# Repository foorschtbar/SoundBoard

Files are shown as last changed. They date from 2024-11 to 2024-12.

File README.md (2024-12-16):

# SoundBoard

A simple PCB with two audio drivers, a SD card reader and a ESP32 microcontroller to play sounds via MQTT.

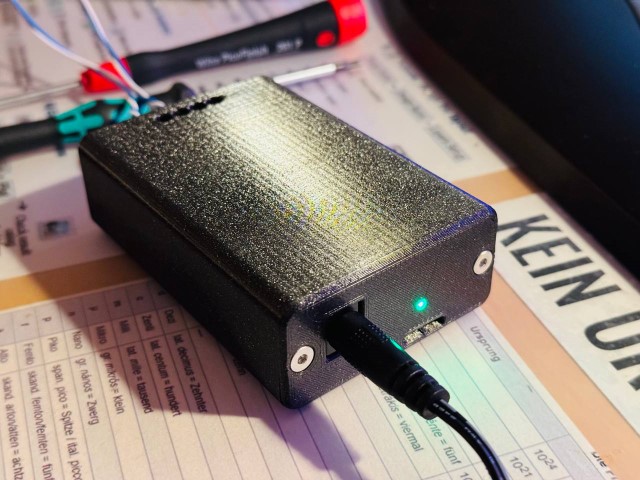
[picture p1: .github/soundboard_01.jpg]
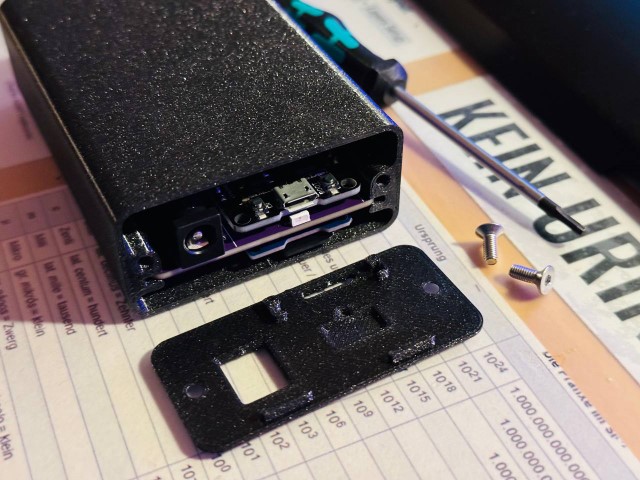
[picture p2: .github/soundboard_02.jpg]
 
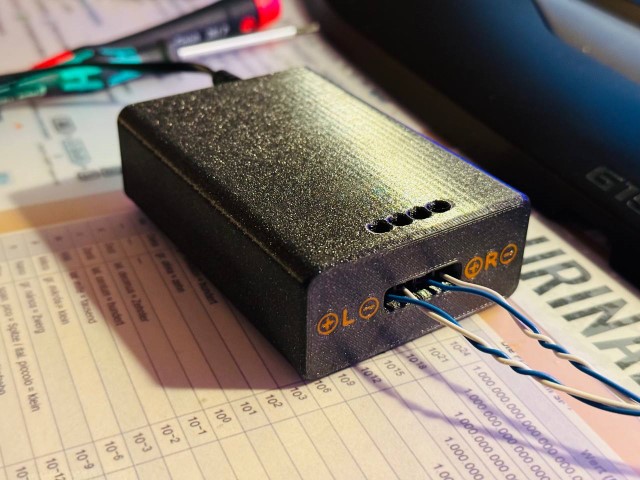
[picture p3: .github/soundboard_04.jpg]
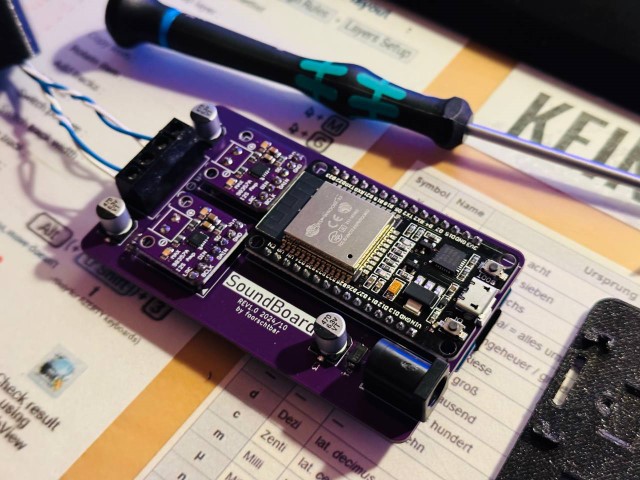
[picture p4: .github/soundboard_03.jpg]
 
## Features
- On factory settings or no known WiFi SSID is found, device starts in AP mode
  - To stay in AP mode, leave the SSID and password empty
- The LED show the status of the device
  - `Orange`: Booting
  - `Blue`: Connecting to WiFi
  - `Green`: Connected to existing WiFi
  - `Violet`: Started WiFi AP
  - `Red`: No connection to WiFi
  - `White`: Web or MQTT activity
- The device can be controlled via MQTT:
  - Subscripte to `<prefix>/status` to get the status of the device
  - Publish to `<prefix>/cmd` to play a sound
    - `{"play": "filename.mp3", "volume": 50, "balance": 0}` (volume and balance are optional)
    - `{"tts": "Hello World", "lang": "de"}`

## Getting Started

- Default WiFi SSID: `SoundBoard`
- Default WiFi Password: `12345678x!`
  
## Hardware

### Case

- The case could be found on [Printables](https://www.printables.com/model/1072334-soundboard).

### PCB

- The PCB was designed with KiCad and could be found in the `pcb` directory.

## Development
### Frontend development

- Start the frontend development server with `python .\webserver.py` in the `html` directory.
- Open the browser at `http://localhost:8000/` to see the frontend.
- Set manual a cookie with `overwrite-host` to the hostname or ip of the device and reload the page.

### ToDos/Improvement Ideas

- [ ] Add a priority flag to the MQTT messages. Stop the current playback only if the priority is higher than the current one.
- [ ] Sync volume and balance fader across all clients
- [ ] Enable/Disable Playback/Stop buttons based on the current state
- [ ] Add addidtional MQTT topics with hostname for status und command
- [ ] Refactor Code in more separat files
- [ ] Maybe: Option to queue playbacks
- [x] Send file list in multiple messages
- [x] If we had valid settings, but in fallback AP mode, try to connect to the last known wifi periodically
- [x] Download audiofiles from the webinterface
- [x] Replace play/delete/download with icons?
- [x] Add tailing slash to the topic prefix
- [x] Save authentication in cookie/webstore
- [x] Add credentials to post requests
- [x] Improve MQTT reconnection and resubscription
- [x] Improve MQTT reconnection after boot when no connection is available
- [x] Make MQTT status topic more "chatty"

## Links
- [ESP32 Based Internet Radio using MAX98357A I2S Amplifier Board](https://circuitdigest.com/microcontroller-projects/esp32-based-internet-radio-using-max98357a-i2s-amplifier-board)
- [I2S Sound Tutorial for ESP32 - DIYI0T](https://diyi0t.com/i2s-sound-tutorial-for-esp32/)
- [schreibfaul1/ESP32-audioI2S: Play mp3 files from SD via I2S](https://github.com/schreibfaul1/ESP32-audioI2S)
- [ESP32 Pinout Reference: Which GPIO pins should you use? | Random Nerd Tutorials](https://randomnerdtutorials.com/esp32-pinout-reference-gpios/)
- [ESP32 partition calculator: Easily Calculate ESP32 Memory and Partition Sizes](https://esp32.jgarrettcorbin.com/)

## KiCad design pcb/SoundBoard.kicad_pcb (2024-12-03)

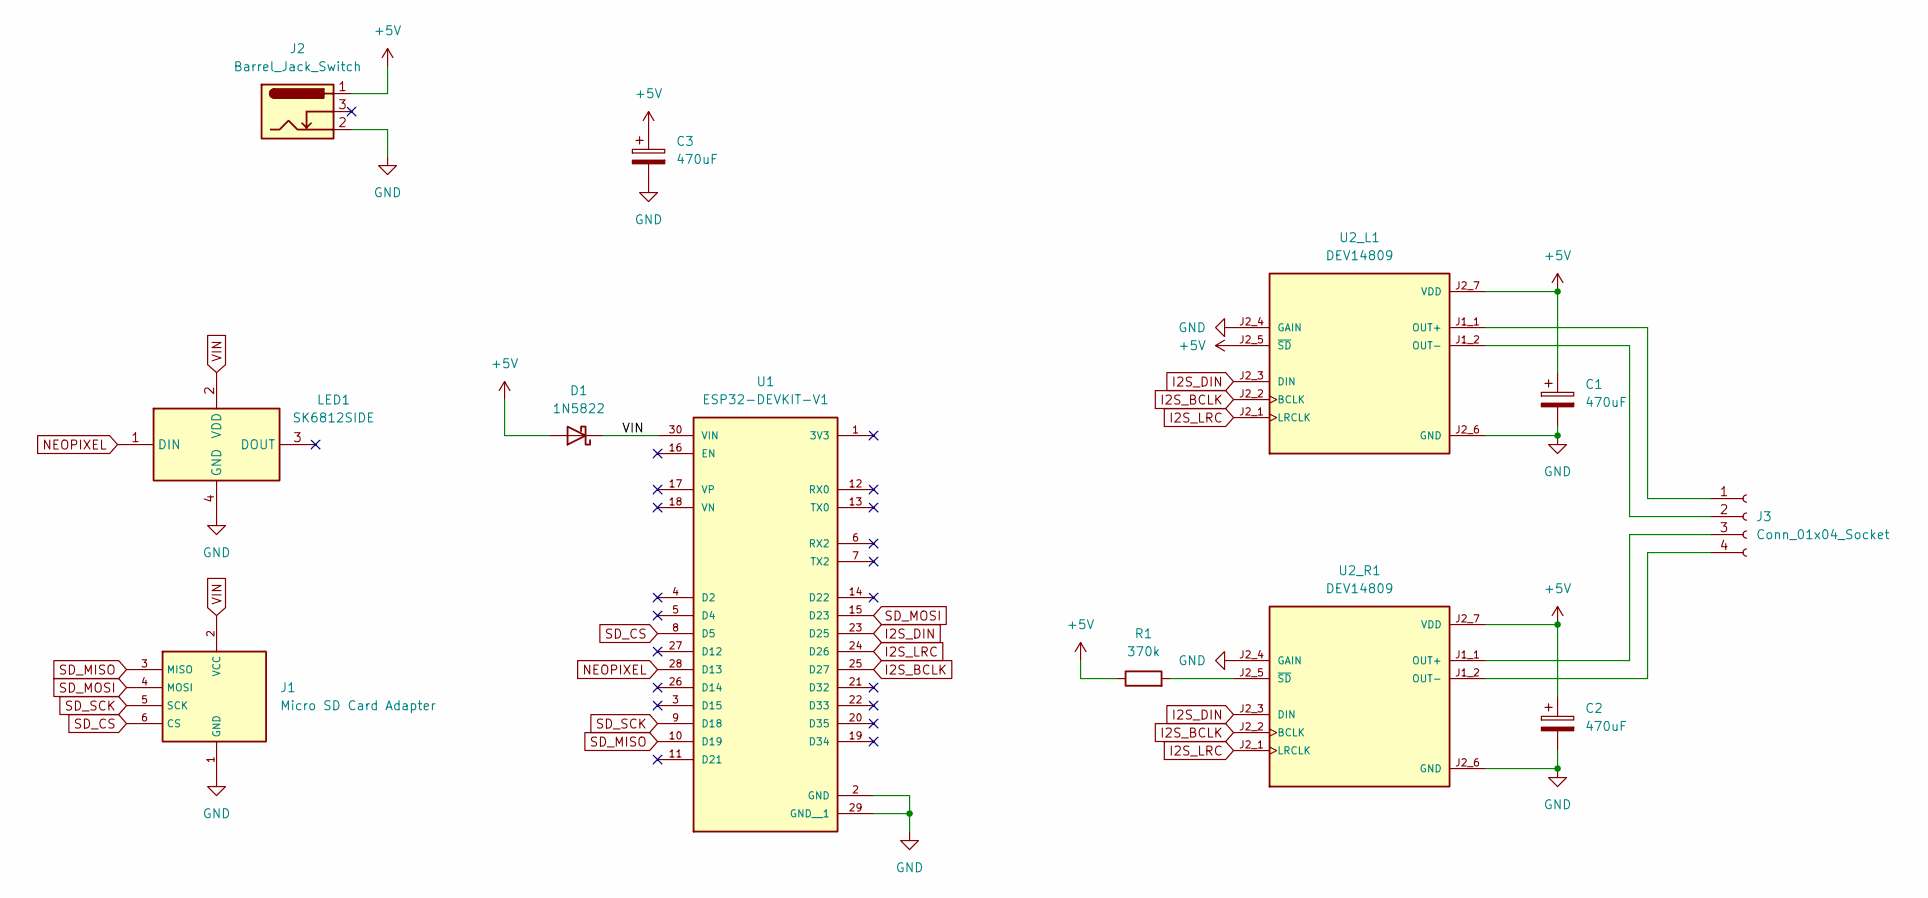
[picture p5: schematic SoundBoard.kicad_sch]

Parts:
C1, C2, C3: 470uF; C_Elec_6.3x7.7
D1: 1N5822; D_SMA_Handsoldering
J1: Micro SD Card Adapter; SDCardAdapter
J2: Barrel_Jack_Switch; BarrelJack_Horizontal
J3: Conn_01x04_Socket; TerminalBlock_Phoenix_MKDS-1,5-4-5.08_1x04_P5.08mm_Horizont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
LED1: SK6812SIDE; Manufacturer_Part_Number SK6812SIDE
R1: 370k; R_0805_2012Metric_Pad1.20x1.40mm_HandSolder
U1: ESP32-DEVKIT-V1; ESP32_DEVKIT_V1; PARTREV N/A
U2_L1, U2_R1: DEV14809; MAX98357A; PARTREV 1.2

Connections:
+5V: C1.1, C2.1, C3.1, D1.2 (A), J2.1, R1.1, U2_L1.J2_5 (~SD), U2_L1.J2_7 (VDD), U2_R1.J2_7 (VDD)
GND: C1.2, C2.2, C3.2, J1.1 (GND), J2.2, LED1.4 (GND), U1.2 (GND), U1.29 (GND__1), U2_L1.J2_4 (GAIN), U2_L1.J2_6 (GND), U2_R1.J2_4 (GAIN), U2_R1.J2_6 (GND)
I2S_BCLK: U1.25 (D27), U2_L1.J2_2 (BCLK), U2_R1.J2_2 (BCLK)
I2S_DIN: U1.23 (D25), U2_L1.J2_3 (DIN), U2_R1.J2_3 (DIN)
I2S_LRC: U1.24 (D26), U2_L1.J2_1 (LRCLK), U2_R1.J2_1 (LRCLK)
NEOPIXEL: LED1.1 (DIN), U1.28 (D13)
unnamed: J3.1, U2_L1.J1_1 (OUT+)
unnamed: J3.2, U2_L1.J1_2 (OUT-)
unnamed: J3.3, U2_R1.J1_1 (OUT+)
unnamed: J3.4, U2_R1.J1_2 (OUT-)
unnamed: R1.2, U2_R1.J2_5 (~SD)
SD_CS: J1.6 (CS), U1.8 (D5)
SD_MISO: J1.3 (MISO), U1.10 (D19)
SD_MOSI: J1.4 (MOSI), U1.15 (D23)
SD_SCK: J1.5 (SCK), U1.9 (D18)
VIN: D1.1 (K), J1.2 (VCC), LED1.2 (VDD), U1.30 (VIN)

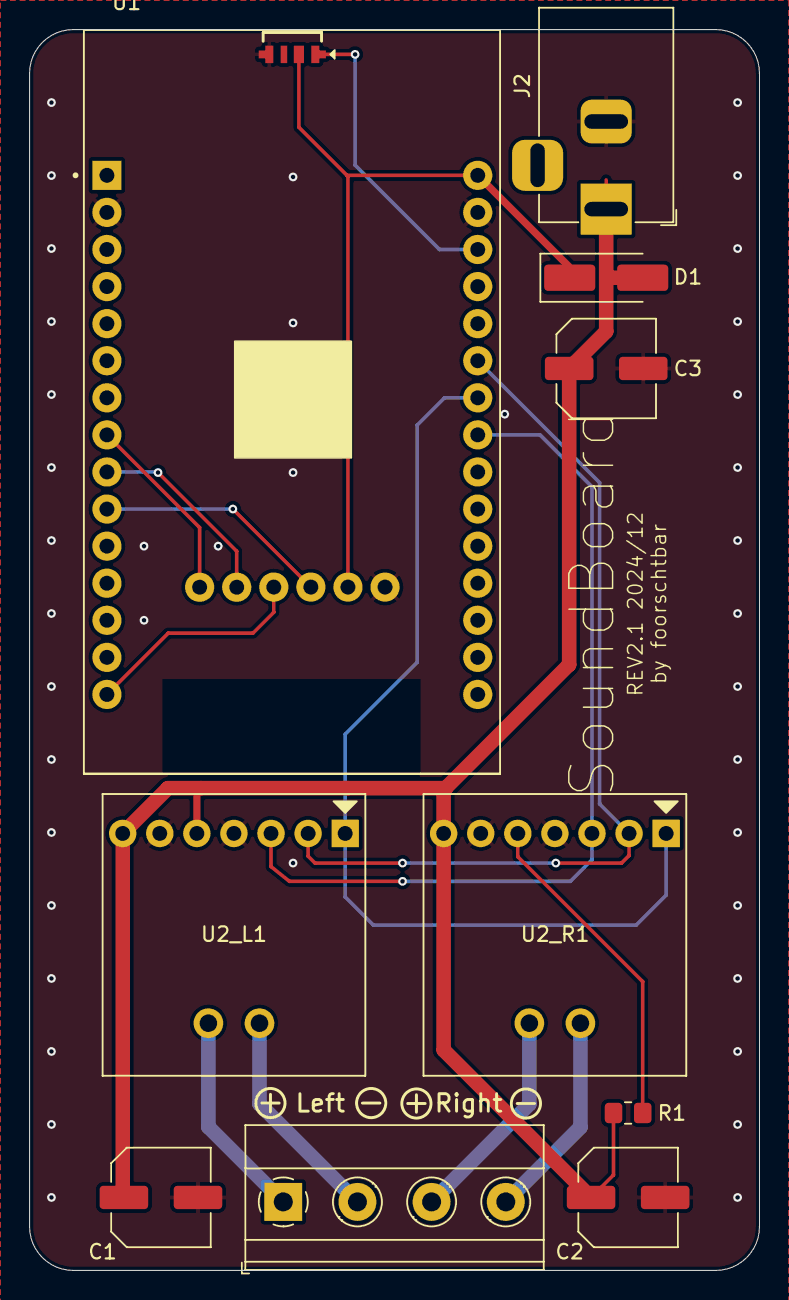
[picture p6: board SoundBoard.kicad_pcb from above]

Board: 2 copper layers, 50.0 x 85.0 mm, 12 parts (1 on the bottom side), 16 nets.

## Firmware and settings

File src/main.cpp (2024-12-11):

#include "Arduino.h"
#include <ArduinoJson.h>
#include "Audio.h"
#include "SD.h"
#include <LittleFS.h>
#include <AsyncTCP.h>
#include <ESPAsyncWebServer.h>
#include <Update.h>
#include <SPI.h>
#include <FS.h>
#include "SingleLED.h"
#include "util.h"
// #include <index.h>
#include <mqtt.h>
#include "esp32/rom/rtc.h"

// I2S Pins
#define I2S_DOUT 25
#define I2S_LRC 26
#define I2S_BCLK 27
// SD Card Pins
#define SD_CS 5
#define SPI_SCK 18
#define SPI_MISO 19
#define SPI_MOSI 23
// Other Pins
#define LED 2 // Blue onboard LED
#define NEOPIXEL 13

// Defaul values
#define BRIGHTNESS_DEFAULT 50
#define DEFAULT_HOSTNAME "SoundBoard"
#define WIFI_AP_SSID "SoundBoard"
#define WIFI_AP_PSK "12345678x!"
#define WIFI_TIMEOUT 1000 * 10               // 10 seconds
#define WIFI_RECONNECT_TIMEOUT 1000 * 60 * 5 // 5 minutes
#define PASSWORD_HIDDEN "**********"
#define MQTT_TOPIC_CMD "cmd"
#define MQTT_TOPIC_STATUS "status"
#define SYSINFO_UPDATE_INTERVAL 1000 * 30
#define FILELIST_CHUNK_SIZE 10
#define DEFAULT_USERNAME "admin"
#define DEFAULT_PASSWORD "admin"
#define DEFAULT_VOLUME 5
#define DEFAULT_BALANCE 0
#define DEFAULT_MQTT_TOPIC_PREFIX "soundboard/"
#define DEFAULT_MQTT_PORT "1883"

// Audioplay
Audio audio;
// LED
SingleLED led(NEOPIXEL, NEO_GRB + NEO_KHZ800);
// MQTT Client
WiFiClient espClient;
MQTT mqtt(espClient);

// Webserver
AsyncWebServer server(80);
AsyncWebSocket websocket("/ws");
std::vector<uint32_t> authenticatedClients;

// Variables
int currentVolume = DEFAULT_VOLUME;
int currentBalance = DEFAULT_BALANCE;

// Settings
bool settingsValid = false;
String settings_ssid;
String settings_psk;
String settings_hostname = DEFAULT_HOSTNAME;
String settings_mqtt_broker;
String settings_mqtt_port = DEFAULT_MQTT_PORT;
String settings_mqtt_user;
String settings_mqtt_pass;
String settings_mqtt_prefix = DEFAULT_MQTT_TOPIC_PREFIX;
String settings_username = DEFAULT_USERNAME;
String settings_password = DEFAULT_PASSWORD;
int settings_volume = DEFAULT_VOLUME;   // 0-21
int settings_balance = DEFAULT_BALANCE; // -16 to 16
bool shouldReboot = false;              // flag to use from web update to reboot the ESP
unsigned long lastSysInfoUpdate = 0;
unsigned long lastWifiReconnect = 0;
bool fsInternalMounted = false;
bool fsExternalMounted = false;

extern const uint8_t file_index_html_start[] asm("_binary_html_index_html_gz_start");
extern const uint8_t file_index_html_end[] asm("_binary_html_index_html_gz_end");

typedef enum DATA_TYPE
{
  DATA_SYSINFO,
  DATA_ALL,
  DATA_FILES
} sendDataType;

void showAction()
{
  led.blink(100, 255, 255, 255);
}

void readSettings()
{

  if (!FILESYSTEM.exists("/settings.json"))
  {
    logln(F("Settings file not found"));
    return;
  }

  // Open the file for reading
  File file = FILESYSTEM.open("/settings.json", "r");

  if (!file)
  {
    logln(F("Failed to open file for reading"));
    return;
  }

  // Allocate a temporary JsonDocument
  StaticJsonDocument<512> doc;

  // Parse the JSON data from the file
  DeserializationError error = deserializeJson(doc, file);

  if (error)
  {
    logln(F("Failed to parse JSON"));
    return;
  }
  else
  {
    if (doc.containsKey("ssid"))
    {
      settings_ssid = doc["ssid"].as<String>();
    }
    if (doc.containsKey("psk"))
    {
      settings_psk = doc["psk"].as<String>();
    }
    if (doc.containsKey("hostname"))
    {
      settings_hostname = doc["hostname"].as<String>();
    }
    if (doc.containsKey("username"))
    {
      settings_username = doc["username"].as<String>();
    }
    if (doc.containsKey("password"))
    {
      settings_password = doc["password"].as<String>();
    }
    if (doc.containsKey("volume"))
    {
      settings_volume = doc["volume"].as<int>();
      currentVolume = settings_volume;
    }
    if (doc.containsKey("balance"))
    {
      settings_balance = doc["balance"].as<int>();
      currentBalance = settings_balance;
    }
    if (doc.containsKey("mqtt_broker"))
    {
      settings_mqtt_broker = doc["mqtt_broker"].as<String>();
    }
    if (doc.containsKey("mqtt_port"))
    {
      settings_mqtt_port = doc["mqtt_port"].as<String>();
    }
    if (doc.containsKey("mqtt_user"))
    {
      settings_mqtt_user = doc["mqtt_user"].as<String>();
    }
    if (doc.containsKey("mqtt_pass"))
    {
      settings_mqtt_pass = doc["mqtt_pass"].as<String>();
    }
    if (doc.containsKey("mqtt_prefix"))
    {
      settings_mqtt_prefix = doc["mqtt_prefix"].as<String>();
    }

    settingsValid = true;
  }

  // Close the file
  file.close();
}

void writeSettings()
{
  // Allocate a temporary JsonDocument
  StaticJsonDocument<512> doc;

  doc["ssid"] = settings_ssid;
  doc["psk"] = settings_psk;
  doc["hostname"] = settings_hostname;
  doc["username"] = settings_username;
  doc["password"] = settings_password;
  doc["volume"] = settings_volume;
  doc["balance"] = settings_balance;
  doc["mqtt_broker"] = settings_mqtt_broker;
  doc["mqtt_port"] = settings_mqtt_port;
  doc["mqtt_user"] = settings_mqtt_user;
  doc["mqtt_pass"] = settings_mqtt_pass;

  // trim mqtt_prefix
  settings_mqtt_prefix.trim();
  // check if mqtt_prefix ends with a slash
  if (settings_mqtt_prefix[settings_mqtt_prefix.length() - 1] != '/')
  {
    settings_mqtt_prefix += "/";
  }
  doc["mqtt_prefix"] = settings_mqtt_prefix;

  // Open the file for writing
  File file = FILESYSTEM.open("/settings.json", "w");
  if (!file)
  {
    logln(F("Failed to open file for writing"));
    return;
  }

  // Serialize JSON to file
  if (serializeJson(doc, file) == 0)
  {
    logln(F("Failed to write to file"));
  }
}

bool checkCredentials(AsyncWebServerRequest *request)
{
  if (request->authenticate(settings_username.c_str(), settings_password.c_str()))
  {
    return true;
  }

  AsyncWebServerResponse *r = request->beginResponse(401);

  // WebAPI should set the X-Requested-With to prevent browser internal auth dialogs
  if (!request->hasHeader("X-Requested-With"))
  {
    r->addHeader("WWW-Authenticate", "Basic realm=\"Login Required\"");
  }
  request->send(r);

  return false;
}

void textAllAuthenticatedClients(const String &message)
{
  for (uint32_t clientid : authenticatedClients)
  {
    websocket.text(clientid, message);
  }
}

void sendStatus(String status)
{
  showAction();
  websocket.textAll("{\"status\":\"" + status + "\"}");
  if (mqtt.isConnected())
  {
    mqtt.publish(MQTT_TOPIC_STATUS, ("{\"status\":\"" + status + "\"}").c_str());
  }
}

void sendPopup(String msg, String icon = "loading", int refresh = 0)
{
  showAction();
  textAllAuthenticatedClients("{\"popup\":\"" + msg + "\", \"icon\":\"" + icon + "\", \"refresh\":" + String(refresh) + "}");
}

void sendData(sendDataType type, String requestID = "", uint32_t offset = 0)
{
  showAction();
  // Create a JSON document
  StaticJsonDocument<3000> doc;

  doc["requestID"] = requestID;

  if (type == DATA_SYSINFO || type == DATA_ALL)
  {

    JsonObject sysinfo = doc.createNestedObject("sysinfo");
    sysinfo["Hostname"] = settings_hostname;
    sysinfo["Uptime"] = millisToTime(millis());
    sysinfo["CPU0 reset reason"] = resetReason(rtc_get_reset_reason(0));
    sysinfo["CPU1 reset reason"] = resetReason(rtc_get_reset_reason(1));
    sysinfo["MQTT"] = (mqtt.isConnected() ? "Connected" : "Disconnected (" + String(mqtt.state()) + ")");
    if (fsInternalMounted)
    {
      sysinfo["FS (internal)"] = String(formatFileSize(FILESYSTEM.usedBytes())) + "/" + String(formatFileSize(FILESYSTEM.totalBytes())) + " (" + String(FILESYSTEM.usedBytes() / (float)FILESYSTEM.totalBytes() * 100.0) + "%)";
    }
    else
    {
      sysinfo["FS (internal)"] = "Not mounted";
    }
    if (fsExternalMounted)
    {
      sysinfo["FS (external)"] = String(formatFileSize(SD.usedBytes())) + "/" + String(formatFileSize(SD.totalBytes())) + " (" + String(SD.usedBytes() / (float)SD.totalBytes() * 100.0) + "%)";
    }
    else
    {
      sysinfo["FS (external)"] = "Not mounted";
    }
    sysinfo["Wifi mode"] = (WiFi.getMode() == WIFI_AP ? "AccessPoint" : (WiFi.getMode() == WIFI_STA ? "Station" : "Unkown"));
    if (WiFi.getMode() == WIFI_STA)
    {
      sysinfo["SSID"] = WiFi.SSID();
      sysinfo["IP address"] = WiFi.localIP().toString();
      sysinfo["Subnet mask"] = WiFi.subnetMask().toString();
      sysinfo["Gateway"] = WiFi.gatewayIP().toString();
      sysinfo["MAC address"] = WiFi.macAddress();
    }
    else if (WiFi.getMode() == WIFI_AP)
    {
      sysinfo["SSID"] = WiFi.softAPSSID();
      sysinfo["IP address"] = WiFi.softAPIP().toString();
      sysinfo["MAC address"] = WiFi.softAPmacAddress();
    }
    sysinfo["WiFi RSSI"] = String(RSSI2Quality(WiFi.RSSI())) + "% (" + String(WiFi.RSSI()) + " dBm)";
    sysinfo["Free Heap"] = ESP.getFreeHeap();
    sysinfo["Free PSRAM"] = ESP.getFreePsram();
    sysinfo["Chip Revision"] = ESP.getChipRevision();
    sysinfo["SDK"] = ESP.getSdkVersion();
    sysinfo["CPU Freq."] = ESP.getCpuFreqMHz();
    sysinfo["Flash Chip Size"] = ESP.getFlashChipSize();
    sysinfo["Compiled"] = String(__DATE__) + " " + String(__TIME__);

    doc["hostname_header"] = settings_hostname;
  }

  if (type == DATA_ALL)
  {

    // Add data to the JSON document
    doc["start_volume"] = settings_volume;
    doc["cur_volume"] = currentVolume;
    doc["start_balance"] = settings_balance;
    doc["cur_balance"] = currentBalance;
    doc["ssid"] = settings_ssid;
    if (settings_psk.length() > 0)
    {
      doc["psk"] = PASSWORD_HIDDEN;
    }
    else
    {
      doc["psk"] = "";
    }
    doc["mqtt_broker"] = settings_mqtt_broker;
    doc["mqtt_port"] = settings_mqtt_port;
    doc["mqtt_user"] = settings_mqtt_user;
    if (settings_mqtt_pass.length() > 0)
    {
      doc["mqtt_pass"] = PASSWORD_HIDDEN;
    }
    else
    {
      doc["mqtt_pass"] = "";
    }
    doc["mqtt_prefix"] = settings_mqtt_prefix;

    if (fsExternalMounted)
    {
      doc["fs_info"] = String(formatFileSize(SD.usedBytes())) + " of " + String(formatFileSize(SD.totalBytes())) + " used (" + String(SD.usedBytes() / (float)SD.totalBytes() * 100.0) + "%)";
    }
    else
    {
      doc["fs_info"] = "Not mounted";
    }
    doc["hostname"] = settings_hostname;
    doc["username"] = settings_username;
    if (settings_password.length() > 0)
    {
      doc["password"] = PASSWORD_HIDDEN;
    }
    else
    {
      doc["password"] = "";
    }
    doc["status"] = "Reeeaaaady...";
  }

  if (type == DATA_FILES || type == DATA_ALL)
  {
    uint32_t count = 0;
    // Filelist
    JsonArray filesArray = doc.createNestedArray("fs");

    if (fsExternalMounted)
    {
      File root = SD.open("/");
      if (!root)
      {
        logln(F("Failed to open directory"));
        return;
      }

      File file = root.openNextFile();
      while (file)
      {
        if (String(file.name()).indexOf("System Volume Information") == -1)
        {
          if (count >= offset && count <= offset + FILELIST_CHUNK_SIZE)
          {
            // Filter System Volume Information

            JsonObject fileObj = filesArray.createNestedObject();
            fileObj["index"] = count;
            fileObj["name"] = String(file.name());
            fileObj["size"] = String(file.size());
          }
          count++;
        }
        file = root.openNextFile();
        if (count >= offset + FILELIST_CHUNK_SIZE)
        {
          if (file)
          {
            JsonObject morefiles = doc.createNestedObject("morefiles");
            morefiles["offset"] = count;
          }
          break;
        }
      }
      root.close();
    }
  }

  // Serialize the JSON document to a string
  String jsonString;
  serializeJson(doc, jsonString);
  if (type == DATA_SYSINFO)
  {
    websocket.textAll(jsonString);
  }
  else
  {
    textAllAuthenticatedClients(jsonString);
  }

  if (mqtt.isConnected() && type == DATA_SYSINFO) // Only short messages are sent to MQTT
  {
    // logf("Sending MQTT status\n");
    // logf("> Length: %i\n", jsonString.length());
    // logf("> Content: %s\n", jsonString.c_str());
    mqtt.publish(MQTT_TOPIC_STATUS, jsonString.c_str());
  }
}

void sendUnauthenticatedData(uint32_t clientid)
{
  sendData(DATA_SYSINFO);
}

void handleMqttMessage(char *topic, byte *payload, unsigned int length)
{
  showAction();
  String status = "";
  logf("handleMqttMessage\n>Content: ");
#ifdef DEBUG
  for (int i = 0; i < length; i++)
  {
    Serial.print((char)payload[i]);
  }
  Serial.println();
#endif
  logf("> Lenght: %i\n", length);
  logf("> Topic: %s\n", topic);

  if (length)
  {
    StaticJsonDocument<256> doc;
    DeserializationError err = deserializeJson(doc, payload);
    if (err)
    {
      logf("> JSON: deserializeJson() failed: %s", err.c_str());
    }
    else
    {
      if (doc.containsKey("volume"))
      {
        currentVolume = doc["volume"].as<int>();
        status = "Volume: " + String(map(currentVolume, 0, 21, 0, 100)) + "%";
        audio.setVolume(currentVolume);
      }
      if (doc.containsKey("balance"))
      {
        currentBalance = doc["balance"].as<int>();
        status = "Balance: " + String(currentBalance);
        audio.setBalance(currentBalance * -1);
      }
      if (doc.containsKey("play"))
      {
        const char *filename = doc["play"].as<const char *>();
        status = "Play " + String(filename);
        audio.stopSong();
        audio.connecttoFS(SD, filename);
      }
      if (doc.containsKey("stop"))
      {
        audio.stopSong();
        status = "Stop";
      }
      if (doc.containsKey("tts") && doc.containsKey("lang"))
      {
        const char *text = doc["tts"].as<const char *>();
        const char *lang = doc["lang"].as<const char *>();

        logf("TTS (%s): %s\n", lang, text);
        audio.stopSong();
        audio.connecttospeech(text, lang);
      }
      if (doc.containsKey("status"))
      {
        sendData(DATA_SYSINFO);
      }
    }
  }

  if (status.length() > 0)
  {
    sendStatus(status);
  }
}

bool checkWSAuth(uint32_t clientid)
{
  if (std::find(authenticatedClients.begin(), authenticatedClients.end(), clientid) == authenticatedClients.end())
  {
    return false;
  }
  else
  {
    return true;
  }
}
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
void loop()
{
  websocket.cleanupClients();
  audio.loop();
  vTaskDelay(1);

  // Disable MQTT in AP mode
  if (WiFi.status() == WL_CONNECTED)
  {
    mqtt.loop();
  }

  // Reboot if we had a SSID configured but are in AP mode
  if (millis() - lastWifiReconnect > WIFI_RECONNECT_TIMEOUT && WiFi.getMode() == WIFI_AP && settings_ssid != "")
  {
    sendStatus("Rebooting to switch to station mode...");
    logln(F("Rebooting to switch to station mode..."));
    shouldReboot = true;
  }

  // Check if we should reboot
  if (shouldReboot)
  {
    logln("> Rebooting...");
    delay(100);
    ESP.restart();
  }

  // send actual system info every x seconds
  // via websocket and MQTT
  if (millis() - lastSysInfoUpdate > SYSINFO_UPDATE_INTERVAL)
  {
    sendData(DATA_SYSINFO);
    lastSysInfoUpdate = millis();
  }

  vTaskDelay(1);
}

// optional
void audio_info(const char *info)
{
#ifdef DEBUG
  Serial.print("info        ");
  Serial.println(info);
#endif
}
void audio_id3data(const char *info)
{ // id3 metadata
#ifdef DEBUG
  Serial.print("id3data     ");
  Serial.println(info);
#endif
}

// end of file
void audio_eof_mp3(const char *info)
{
  logf("audio_eof_mp3: %s\n", info);
  sendStatus("End of file " + String(info));
}

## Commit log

2024-10-11 Inital commit
    [SoundBoard.kicad_pcb, SoundBoard.kicad_sch, partitions.csv]
2024-10-11 Fixed left channel
    [SoundBoard.kicad_sch]
2024-10-13 Fixed WDT Reset problem with SingleLED lib (ocurs on notFound request O.o)
    [main.cpp]
2024-10-16 MQTT improvments
    - Added LWT
    - Added RSSI2Quality
    - Send statusupdates every 30s
    - Bugfixes
    [main.cpp]
2024-10-20 Finished PCB Layout
    [SoundBoard.kicad_pcb, SoundBoard.kicad_sch]
2024-10-26 Fixed problem with heap by moving html content to gziped binary flash content
    [main.cpp]
2024-10-28 Fixed a problem where the LED was getting darker and darker
2024-11-02 Improved PCBs (REV2.0)
    [SoundBoard.kicad_pcb, SoundBoard.kicad_sch]
2024-11-02 Fixed MQTT crash in AP mode
    [main.cpp]
2024-11-02 Updated ESP32-AudioI2S lib
2024-11-02 Added reboot after timeout in AP mode when SSID is configured
    [main.cpp]
2024-12-03 PCB Rev 2.1
    [SoundBoard.kicad_pcb, SoundBoard.kicad_sch]
2024-12-03 Improved FS mounting
2024-12-04 Added playback stop button to WebUI
2024-12-15 Update PCB
